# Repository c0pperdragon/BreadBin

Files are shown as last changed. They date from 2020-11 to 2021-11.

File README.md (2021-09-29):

# BreadBin computer
A CPU made of 7400 logic on breadboards - inside a bread bin ;-) 

## Current design 

After various experiments and failed attempts to design a 7400-based computer, I came to a quite minimalistic
8-bit approach which is nevertheless pretty versatile and can utilize a surprisingly large amount of memory
resources. The CPU core itself executes its program from a static 64K flash memory and can access 32 bytes of
internal RAM (which can be considered registers for all practical purposes). Access to the external memory 
area (up to 16MB of address space) allows addition of RAM, ROM and memory mapped IO. In the current setup this
directly mirrors the capabilities of my [OS816 reference design](https://github.com/c0pperdragon/OS816).

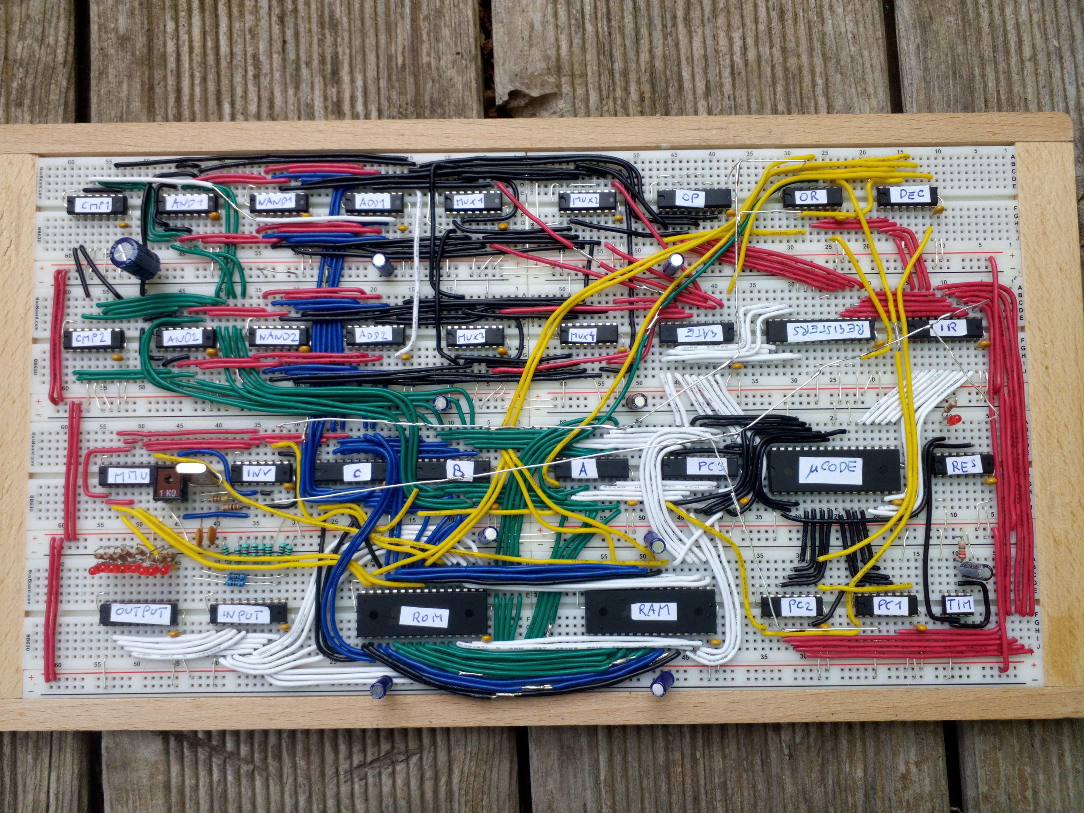
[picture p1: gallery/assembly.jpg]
Breadboard build


## Computer case

With the CPU already built so nicely on an actual wooden board, I had the idea to put it together with
the rest of the computer into a matching bread bin. Because the machine will not require any ventilation this
will keep the dust out quite reliably.

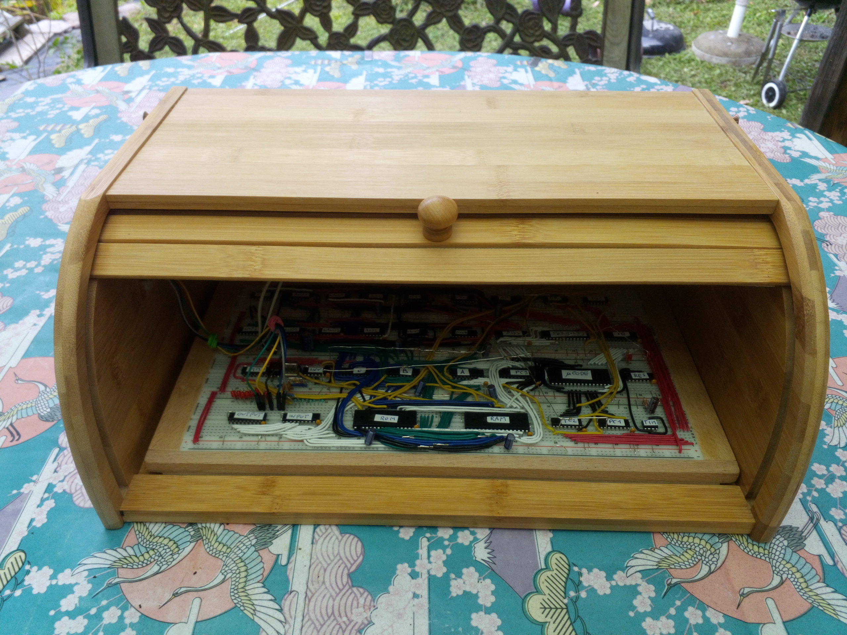
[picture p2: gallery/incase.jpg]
In wooden bread bin

 
## On bread boards

Since a very long time I wanted to design my own CPU and build it from smaller parts, preferable 
on bread boards. My main problem with the approach were my bad experiences with bread boards as a whole,
as they seemed to be too unreliable for anything more serious than arduino tinkering.
As it turns out it is only a matter of using high-quality boards and cabling to get a reliably working
build. The boards I now use (BB830 from BusBoard) are quite expensive, but worth every penny 
and give me very little trouble.

In previous attempts I had much trouble to get a stable ground reference accross all the individual boards.
So this time I directly soldered together ground rails of parallel boards with silver wire on the bottom
and then placed the boards on top of a large plane of aluminium foil. This foil should make good contact to all
the silver ground wires to connect them together and additionally work as shielding. 
So far this works pretty good.

When using this kind of setup it is important to also use a matching logic family of chips. 74AC, 74ACT, 74LVC or 
others have a very fast switching characteristics. This is great for many applications but in a large build with
long and unshielded cables, their brutally steep signal edges wreck havoc with signal integritiy.
So I settled for the moderately fast and well-behaved 74HC logic ICs with only a few 74AC parts to speed up the ALU.

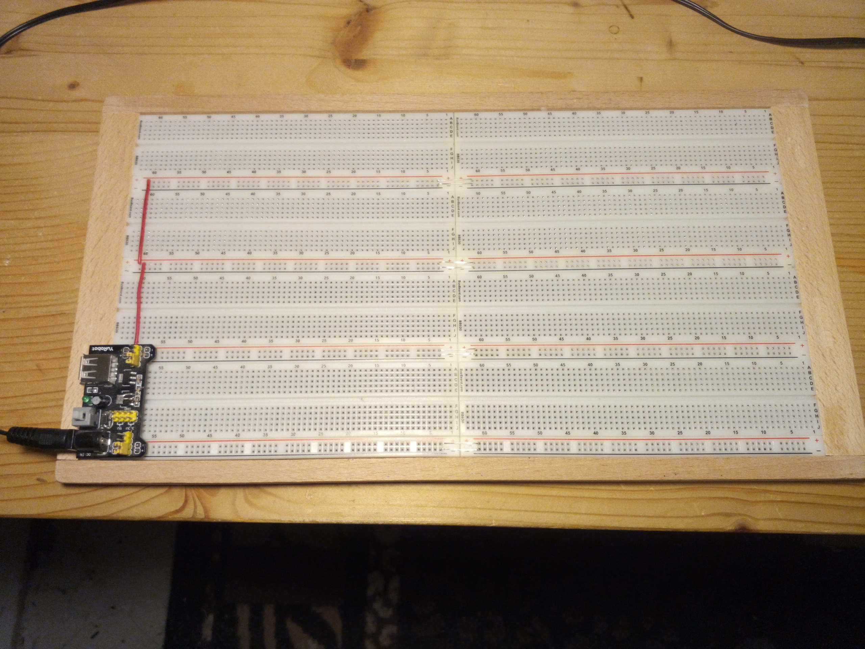
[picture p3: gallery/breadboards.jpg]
Bread boards


## Software

One of the hardest parts of home-made computers is to actually build all the software to make the machine useful.
To get the benefit of existing software, the breadboard computer core is designed to emulate the existing CPU
65C816. Together with 512K RAM and 512K Flash and identical IO capabilities, this now is a completely software 
compatible replica of the OS816 system - running at a lower overall speed, of course.

To properly stay in the "bread" theme, the emulator is called [Bernd](bernd) or BER/ND (if you like a 
more technical appearance). People familiar with the german TV station "Kinderkanal" will recognize the reference.

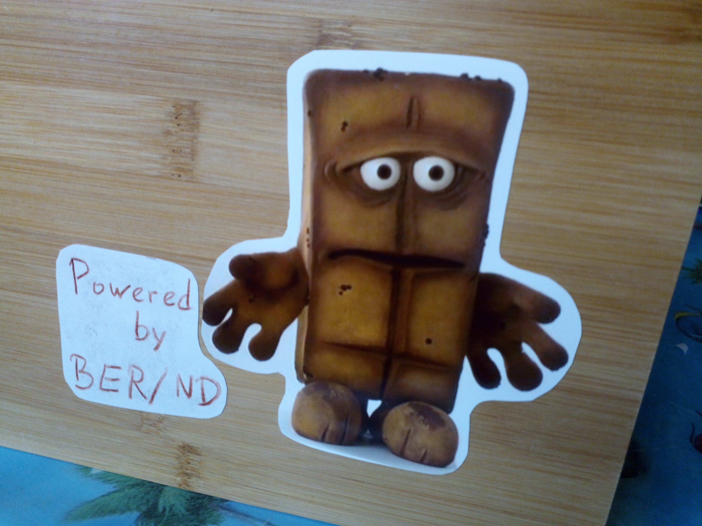
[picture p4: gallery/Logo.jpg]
Bernd logo


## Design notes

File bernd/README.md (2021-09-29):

# BreadBin Emulation Runtime / Nearly Documented

For the BreadBin to be able to execute useful code, it can run BER/ND, which is an instruction-level
emulation of the 65C816 CPU. Execution speed is of course pretty slow compared to a real 65C816, 
but you would not expect top-performance from a bread with such short arms and legs. 
But as long as it gets the job done eventually, this is totally fine by me.

## Unsupported features

To keep the complexity down for the specific purpose of running C programs on the breadbin computer,
some rarely used features and unused features are ommited.

* Emulation mode
* Interrupts (and I flag)
* Decimal mode (and D flag)

## Missing instructions

As a consequence of unsupported features, some opcodes would result in a wrong behaviour.
These opcodes are by design missing from the Bernd emulator and will just cause an immediate processor halt. 

* COP (co-processor interrupt) 
* PLP attempting to set D or I 
* RTI (return from interrupt)
* SED (set decimal)
* SEP attempting to set D or I
* WAI (wait for interrupt)
* XCE attempting to turn on emulation

## Special handling of BRK

As it happens, the BRK instruction has the opcode $00. Executing this opcode causes the Bernd
emulator just to restart, which also resets the emulated 65c816 processor.

## Special use of XCE

Even though emulation is missing and the E flag is not implemented, programms still
need to be able to use the XCE instruction to get into native mode when running on a genuine
65C816 processor. 
To allow this, the XCE instruction when executed by Bernd, is only permitted
to turn off emulation and it will otherwise halt execution.
Additionally it is permitted to turn off emulation repeatedly in which case
the resulting C flag will always be set in the Bernd environment (contrary to 
what it would do on the real processor). 
With this a program can detect when it is running in the Bernd emulator without additional 
preparations.

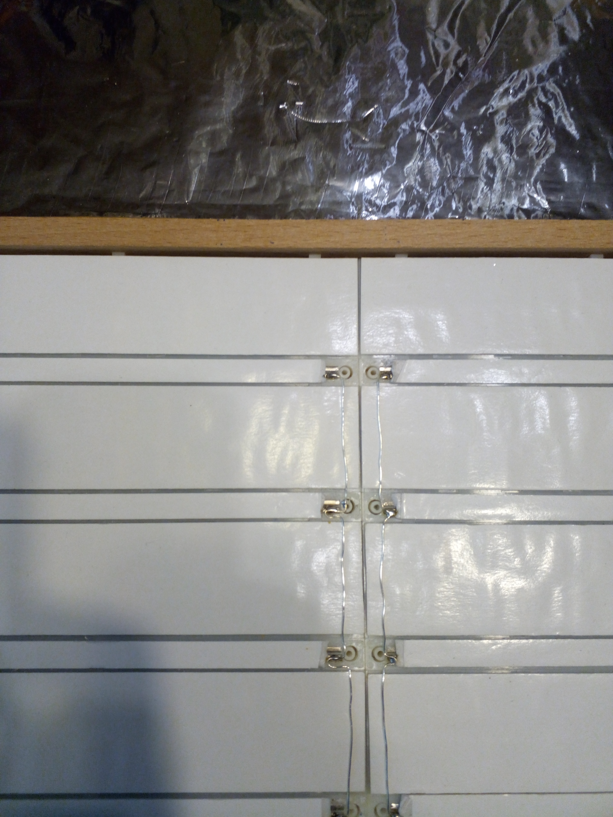
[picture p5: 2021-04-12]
gallery/groundplane.jpg

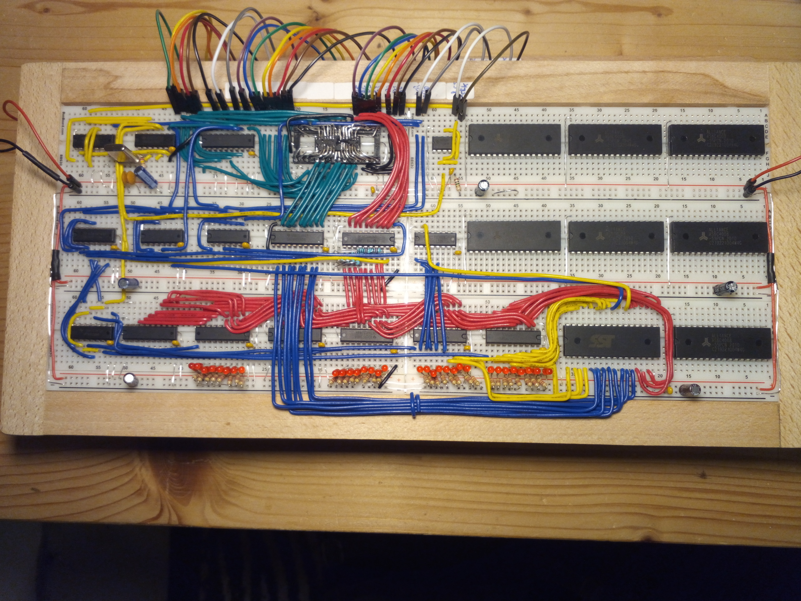
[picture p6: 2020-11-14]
gallery/SystemBoard.jpg

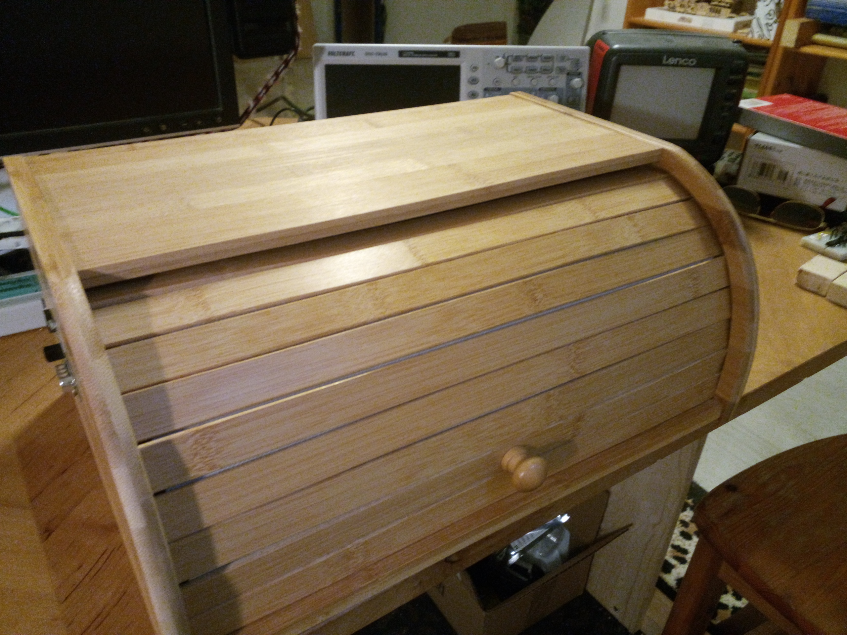
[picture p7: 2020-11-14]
gallery/Case.jpg

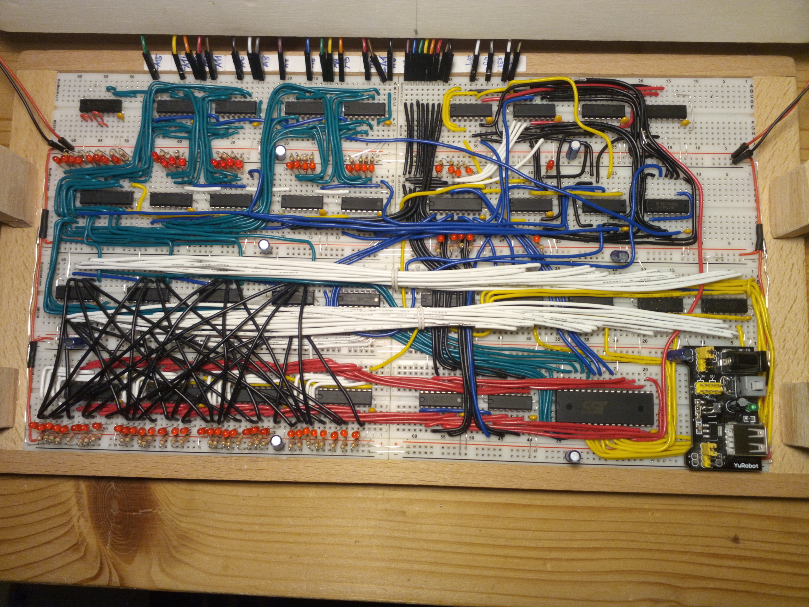
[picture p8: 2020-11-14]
gallery/CPU.jpg

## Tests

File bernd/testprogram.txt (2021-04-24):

; Small test program to use various aspects of the 65C816 to be emulated by Bernd.
; It is small enough so that I do not even use an assembler.
; The program tries to use different parts of the ROM and different parts of the RAM for read and write.
; It also accesses the input and the output port to check if all bits are working.

808000 80 C0 60 30 18 0C 06 03 01 03 06 0C 18 30 60 C0  ; pattern sequence

80FF00 A9 00          LDA #$00         ; initialize counter
80FF02 85 00          STA $00  

80FF04 A5 00          LDA $00          ; read counter from low RAM
80FF06 18             CLC              ; increment up to 15 
80FF07 69 01          ADC #1
80FF09 29 0F          AND #$0F
80FF0B 85 00          STA $00          ; write incremented counter to low RAM
80FF0D AA             TAX

80FF0E A9 40          LDA #$40         ; set up 3. byte of access pointer
80FF10 85 02          STA $02          

80FF12 BF 00 80 80    LDA $808000,X    ; fetch output pattern from ROM
80FF16 8F FF FF 07    STA $07FFFF      ; write to high RAM
80FF2A AF FF FF 07    LDA $07FFFF      ; read from high RAM

80FF1E 2F 00 00 40    AND $400000      ; merge with input data
80FF22 85 01          STA $01          ; set up 2. byte of access pointer, but keep in A also
80FF24 87 00          STA [$00]        ; write via access pointer to output port

80FF26 A9 05          LDA #5           ; waiting loop
80FF28 A0 C8      w0: LDY #200
80FF2A A2 C8      w1: LDX #200
80FF2C E8         w2: INX
80FF2D D0 FD          BNE w2
80FF2F C8             INY
80FF30 D0 F8          BNE w1
80FF32 38             SEC 
80FF33 E9 01          SBC #1
80FF35 D0 F1          BNE w0

80FF37 5C 04 FF 80    JMP $80FF04
          
; Bootstrap code to switch to native mode that can access all RAM and all ROM.
; For Bernd emulation this would not be necessary, but it does not hurt, either.
80FFF0 18             CLC     
80FFF1 FB             XCE              ; turn off emulation mode (X and M flags are still 1)
80FFF2 5C 00 FF 80    JMP $80FF00      ; start user program
80FFF6 FF FF
80FFF8 5C F0 FF 80    JMP $80FFF0      ; first instruction after reset -> jump to native mode ROM area 
80FFFC F8 FF                           ; reset vector is pointing to the initial long jump in bank 0

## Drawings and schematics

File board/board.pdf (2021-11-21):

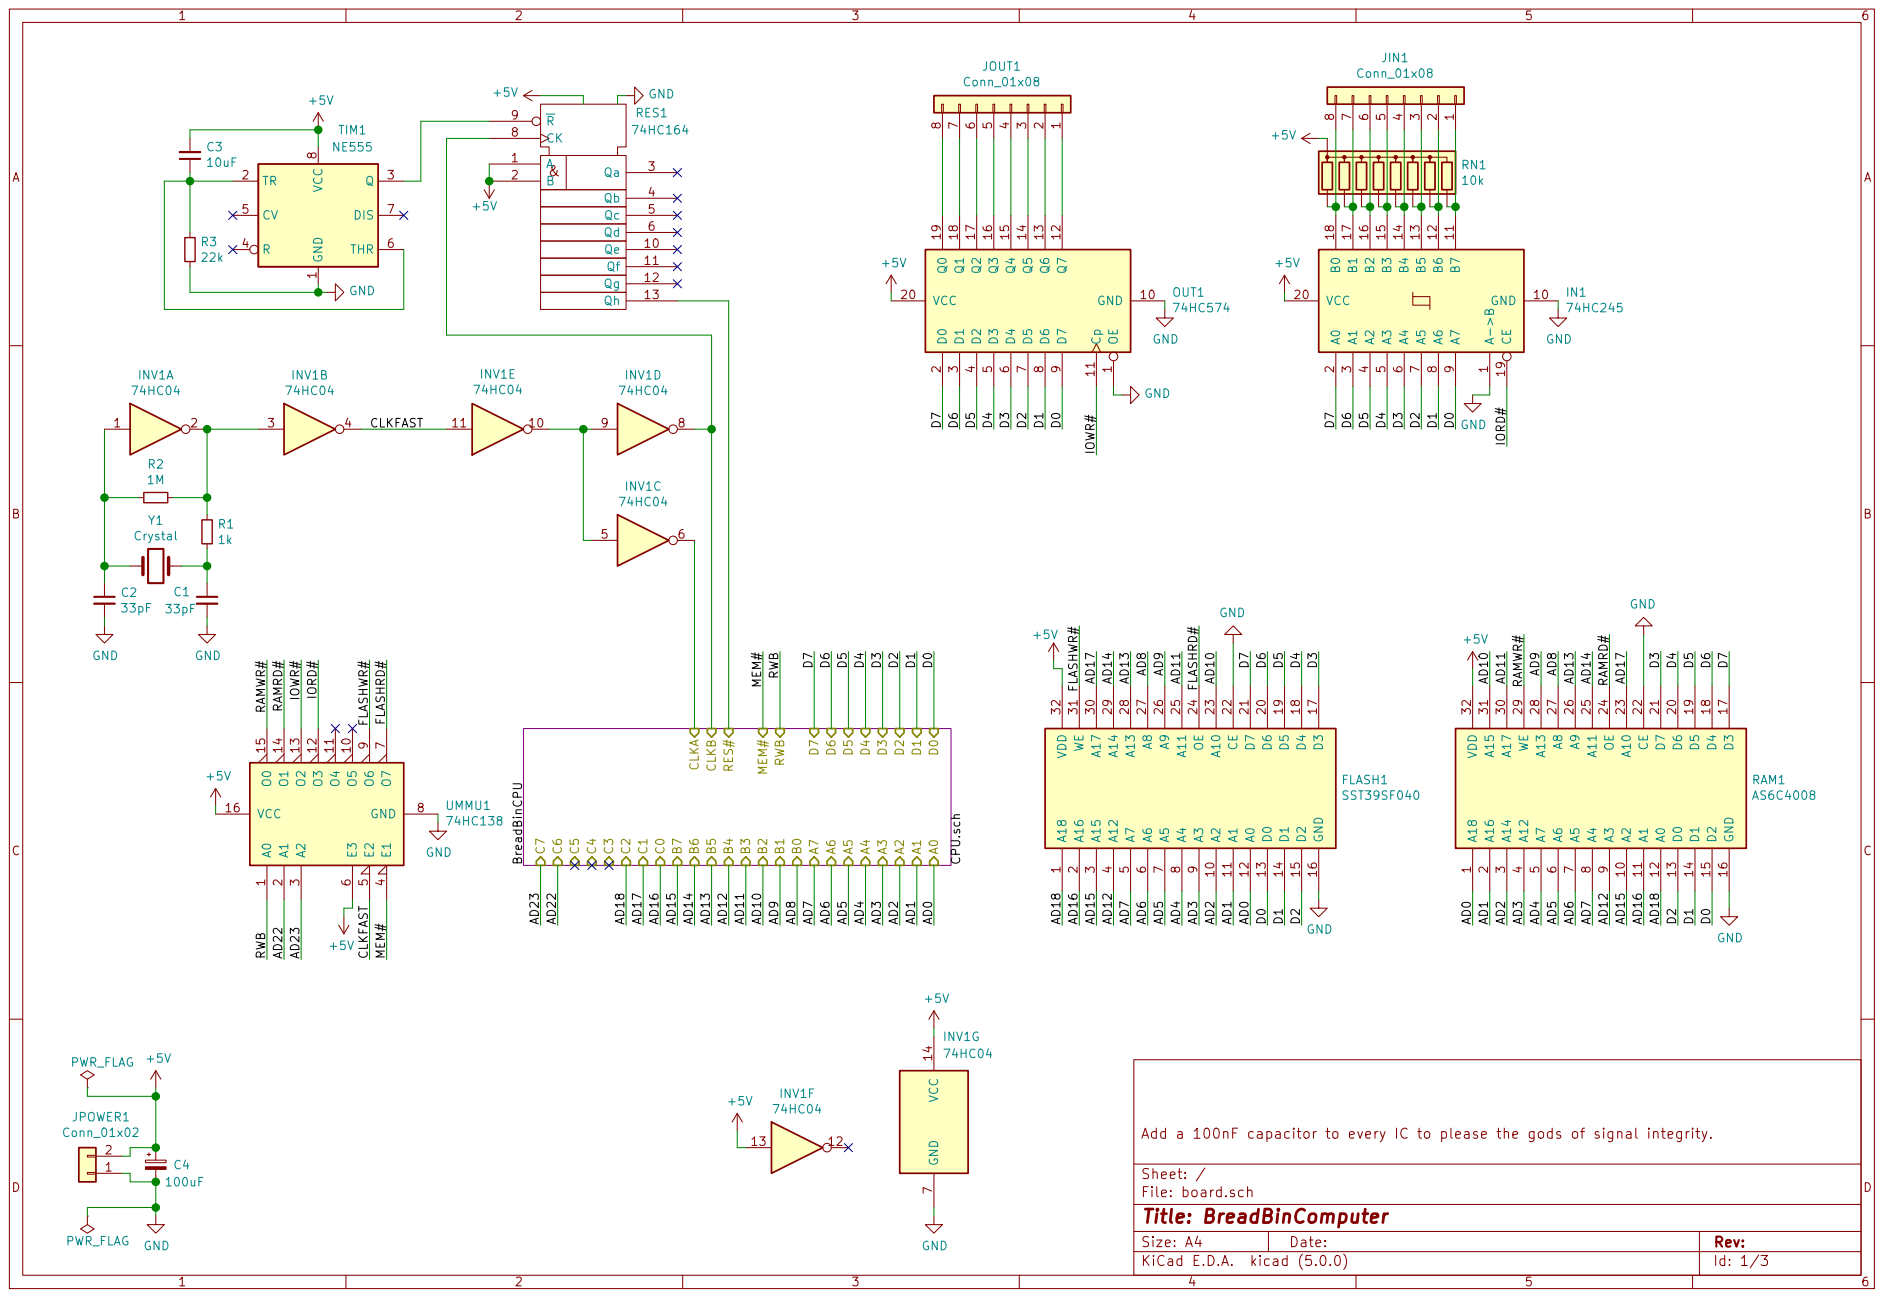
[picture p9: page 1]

Id: 1/3 Title: BreadBinComputer File: board.sch Sheet: / Add a 100nF capacitor to every IC to please the gods of signal integrity. GND

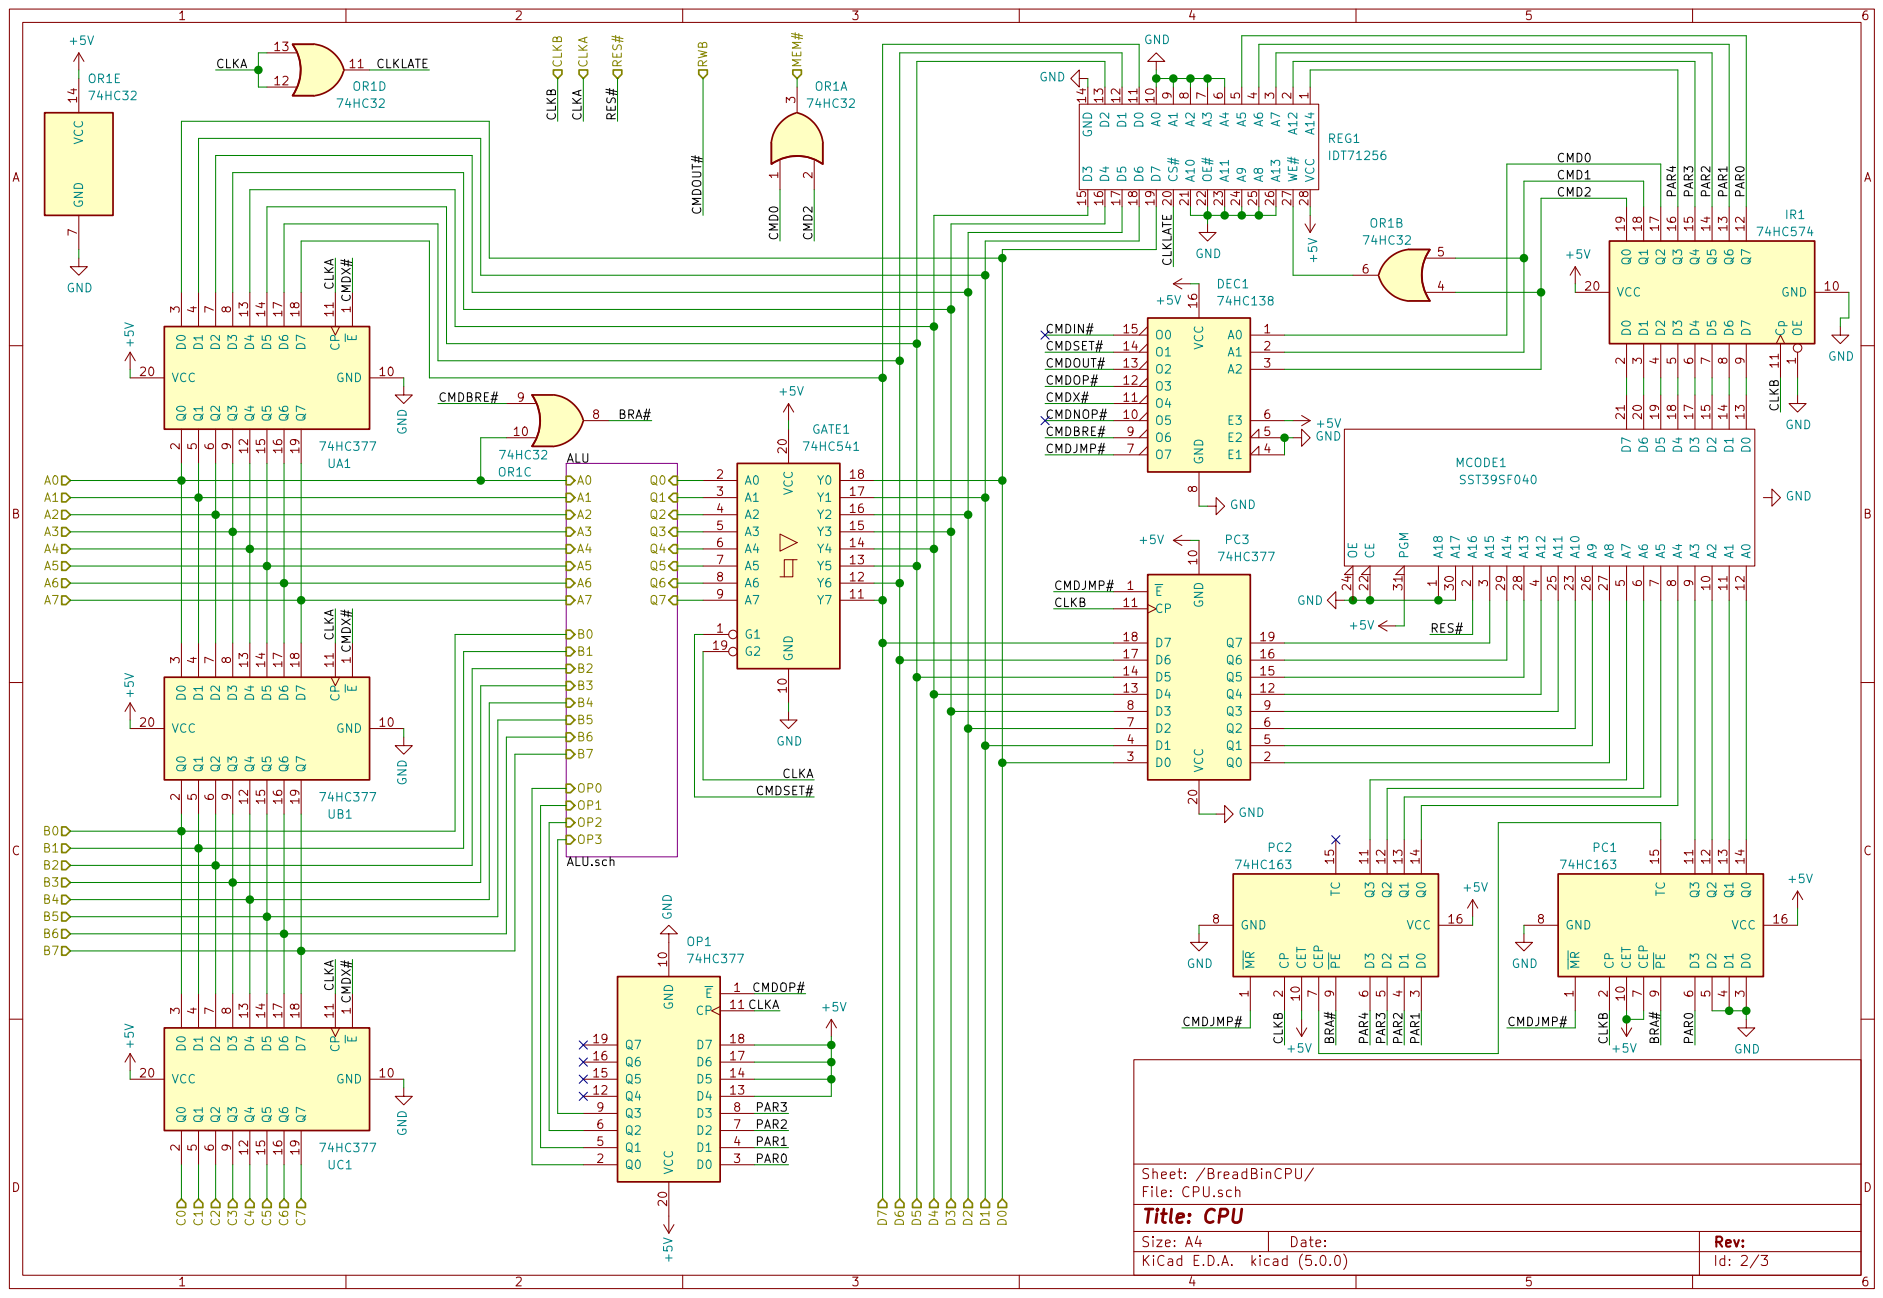
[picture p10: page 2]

2 CS# 20 A10 21 OE# 22 A11 23 A9 24 A8 25 A13 26 WE# 27 VCC 28 A7

1 CET 10 Q3 11 Q2 12 Q1 13 Q0 14 TC 15 VCC 16 CP

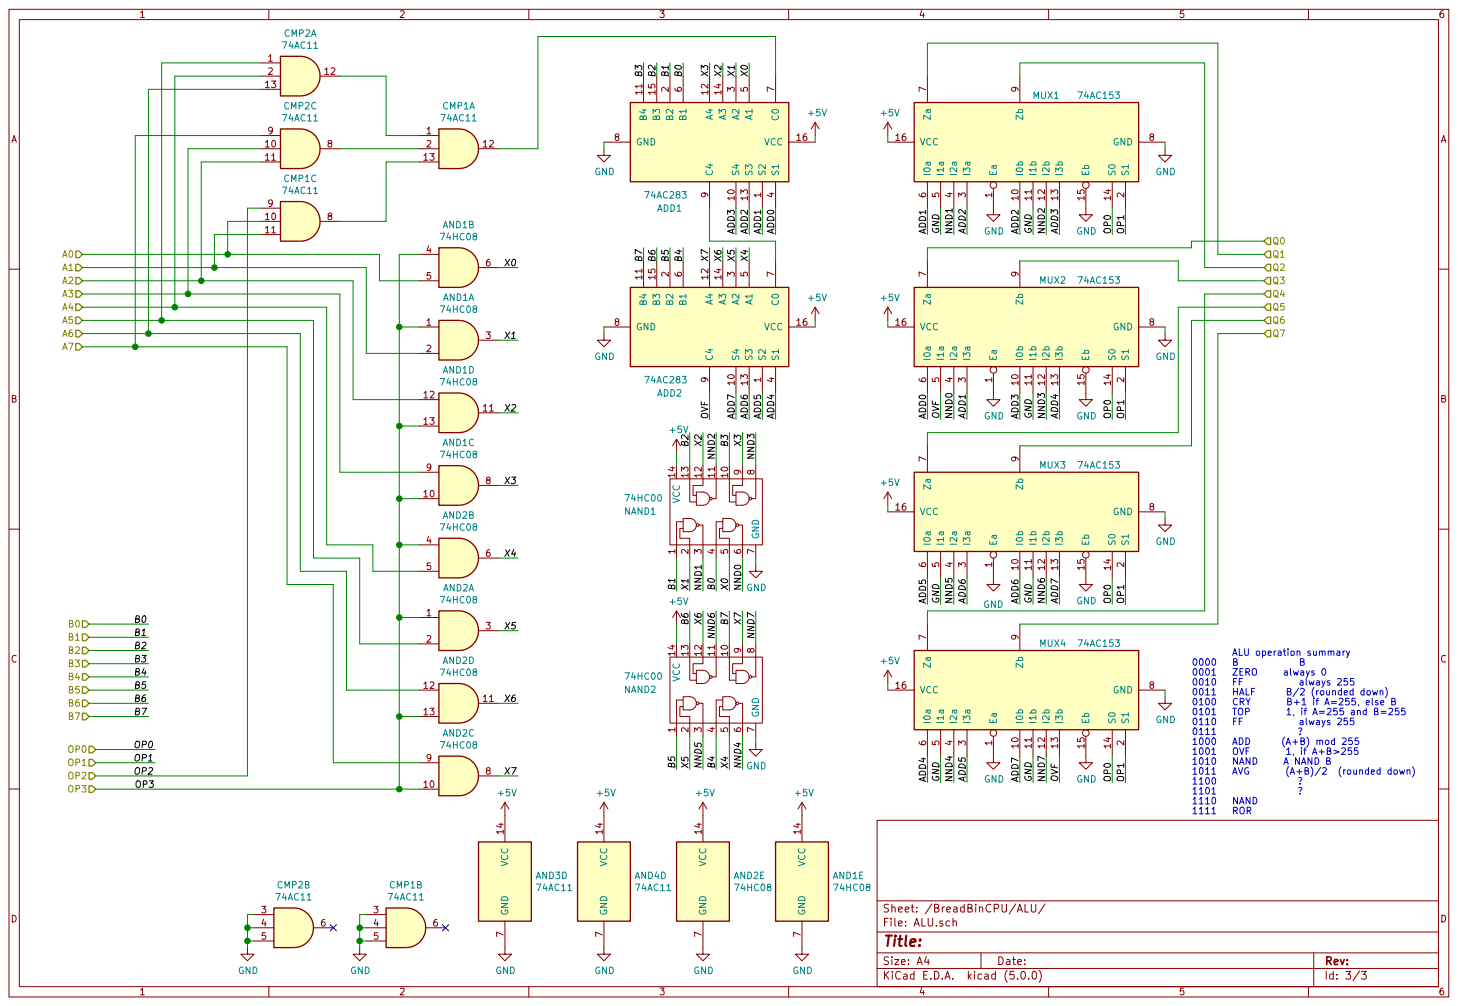
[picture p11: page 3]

Id: 3/3 Title: File: ALU.sch Sheet: /BreadBinCPU/ALU/

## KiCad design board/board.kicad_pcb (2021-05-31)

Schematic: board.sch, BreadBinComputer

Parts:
C1, C2: 33pF; C_Disc_D4.7mm_W2.5mm_P5.00mm
C3: 10uF; C_Disc_D4.7mm_W2.5mm_P5.00mm
C4: 100uF; CP_Radial_D10.0mm_P5.00mm
IN1: 74HC245; DIP-20_W7.62mm
INV1: 74HC04; DIP-14_W7.62mm
JIN1: Conn_01x08; PinHeader_1x08_P2.54mm_Vertical
JOUT1: Conn_01x08; PinHeader_1x08_P2.54mm_Vertical
JPOWER1: Conn_01x02; PinHeader_1x02_P2.54mm_Vertical
OR2: 74HC32; DIP-14_W7.62mm
OUT1: 74HC574; DIP-20_W7.62mm
R1: 1k; R_Axial_DIN0204_L3.6mm_D1.6mm_P7.62mm_Horizontal
R2: 1M; R_Axial_DIN0204_L3.6mm_D1.6mm_P7.62mm_Horizontal
R3: 33k; R_Axial_DIN0204_L3.6mm_D1.6mm_P7.62mm_Horizontal
RAM1: AS6C4008; DIP-32_W15.24mm
RES1: 74HC164; DIP-14_W7.62mm
RN1: 10k; R_Array_SIP9
ROM1: SST39SF040; DIP-32_W15.24mm
TIM1: NE555; DIP-8_W7.62mm
Y1: Crystal; Crystal_HC18-U_Vertical

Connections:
/AD0: RAM1.1, ROM1.12; also elsewhere on the board
/AD1: RAM1.2, ROM1.11; also elsewhere on the board
/AD2: RAM1.3, ROM1.10; also elsewhere on the board
/AD3: RAM1.4, ROM1.9; also elsewhere on the board
/AD4: RAM1.5, ROM1.8; also elsewhere on the board
/AD5: RAM1.6, ROM1.7; also elsewhere on the board
/AD6: RAM1.7, ROM1.6; also elsewhere on the board
/AD7: RAM1.8, ROM1.5; also elsewhere on the board
/AD8: RAM1.27, ROM1.27; also elsewhere on the board
/AD9: RAM1.28, ROM1.26; also elsewhere on the board
/AD10: RAM1.31, ROM1.23; also elsewhere on the board
/AD11: RAM1.30, ROM1.25; also elsewhere on the board
/AD12: RAM1.9, ROM1.4; also elsewhere on the board
/AD13: RAM1.26, ROM1.28; also elsewhere on the board
/AD14: RAM1.25, ROM1.29; also elsewhere on the board
/AD15: RAM1.10, ROM1.3; also elsewhere on the board
/AD16: RAM1.11, ROM1.2; also elsewhere on the board
/AD17: RAM1.23, ROM1.30; also elsewhere on the board
/AD18: RAM1.12, ROM1.1; also elsewhere on the board
/AD22: INV1.13, OR2.1; also elsewhere on the board
/AD23: INV1.11, OR2.2, OR2.4; also elsewhere on the board
/BreadBinCPU/CLK: INV1.6, RES1.8; also elsewhere on the board
/BreadBinCPU/RES#: RES1.13; also elsewhere on the board
/D0: IN1.9 (A7), OUT1.9, RAM1.13, ROM1.13; also elsewhere on the board
/D1: IN1.8 (A6), OUT1.8, RAM1.14, ROM1.14; also elsewhere on the board
/D2: IN1.7 (A5), OUT1.7, RAM1.15, ROM1.15; also elsewhere on the board
/D3: IN1.6 (A4), OUT1.6, RAM1.17, ROM1.17; also elsewhere on the board
/D4: IN1.5 (A3), OUT1.5, RAM1.18, ROM1.18; also elsewhere on the board
/D5: IN1.4 (A2), OUT1.4, RAM1.19, ROM1.19; also elsewhere on the board
/D6: IN1.3 (A1), OUT1.3, RAM1.20, ROM1.20; also elsewhere on the board
/D7: IN1.2 (A0), OUT1.2, RAM1.21, ROM1.21; also elsewhere on the board
/IOSEL#: OR2.6, OR2.9, OR2.12
/RAMSEL#: OR2.3, RAM1.22
/RD#: OR2.13, RAM1.24, ROM1.24; also elsewhere on the board
/ROMSEL#: INV1.10, ROM1.22
/WR#: OR2.10, RAM1.29, ROM1.31; also elsewhere on the board
unnamed: C1.1, R1.2, Y1.2
unnamed: C2.1, INV1.1, R2.2, Y1.1
unnamed: C3.1, R3.1, TIM1.2 (TR), TIM1.6 (THR)
unnamed: IN1.11 (B7), JIN1.1, RN1.9
unnamed: IN1.12 (B6), JIN1.2, RN1.8
unnamed: IN1.13 (B5), JIN1.3, RN1.7
unnamed: IN1.14 (B4), JIN1.4, RN1.6
unnamed: IN1.15 (B3), JIN1.5, RN1.5
unnamed: IN1.16 (B2), JIN1.6, RN1.4
unnamed: IN1.17 (B1), JIN1.7, RN1.3
unnamed: IN1.18 (B0), JIN1.8, RN1.2
unnamed: IN1.19 (CE), OR2.11
unnamed: INV1.2, INV1.3, R1.1, R2.1
unnamed: INV1.4, INV1.5, INV1.9
unnamed: INV1.12, OR2.5
unnamed: JOUT1.1, OUT1.12
unnamed: JOUT1.2, OUT1.13
unnamed: JOUT1.3, OUT1.14
unnamed: JOUT1.4, OUT1.15
unnamed: JOUT1.5, OUT1.16
unnamed: JOUT1.6, OUT1.17
unnamed: JOUT1.7, OUT1.18
unnamed: JOUT1.8, OUT1.19
unnamed: OR2.8, OUT1.11
unnamed: RES1.9, TIM1.3 (Q)

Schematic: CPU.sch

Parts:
DEC1: 74HC138; DIP-16_W7.62mm
GATE1: 74HC541; DIP-20_W7.62mm
IR1: 74HC574; DIP-20_W7.62mm
MCODE1: SST39SF040; DIP-32_W15.24mm
OP1: 74HC377; DIP-20_W7.62mm
OR1: 74HC32; DIP-14_W7.62mm
PC1, PC2: 74HC163; DIP-16_W7.62mm
PC3: 74HC377; DIP-20_W7.62mm
REG1: IDT71256; DIP-28_W7.62mm
UA1: 74HC377; DIP-20_W7.62mm
UB1: 74HC377; DIP-20_W7.62mm
UC1: 74HC377; DIP-20_W7.62mm

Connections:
/AD0: OR1.10, UA1.2, UB1.3; also elsewhere on the board
/AD1: UA1.5, UB1.4; also elsewhere on the board
/AD2: UA1.6, UB1.7; also elsewhere on the board
/AD3: UA1.9, UB1.8; also elsewhere on the board
/AD4: UA1.12, UB1.13; also elsewhere on the board
/AD5: UA1.15, UB1.14; also elsewhere on the board
/AD6: UA1.16, UB1.17; also elsewhere on the board
/AD7: UA1.19, UB1.18; also elsewhere on the board
/AD8: UB1.2, UC1.3; also elsewhere on the board
/AD9: UB1.5, UC1.4; also elsewhere on the board
/AD10: UB1.6, UC1.7; also elsewhere on the board
/AD11: UB1.9, UC1.8; also elsewhere on the board
/AD12: UB1.12, UC1.13; also elsewhere on the board
/AD13: UB1.15, UC1.14; also elsewhere on the board
/AD14: UB1.16, UC1.17; also elsewhere on the board
/AD15: UB1.19, UC1.18; also elsewhere on the board
/AD16: UC1.2; also elsewhere on the board
/AD17: UC1.5; also elsewhere on the board
/AD18: UC1.6; also elsewhere on the board
/AD22: UC1.16; also elsewhere on the board
/AD23: UC1.19; also elsewhere on the board
/BreadBinCPU/ALU/OP0: OP1.9; also elsewhere on the board
/BreadBinCPU/ALU/OP1: OP1.6; also elsewhere on the board
/BreadBinCPU/ALU/OP2: OP1.5; also elsewhere on the board
/BreadBinCPU/ALU/OP3: OP1.2; also elsewhere on the board
/BreadBinCPU/ALU/Q0: GATE1.2 (A0); also elsewhere on the board
/BreadBinCPU/ALU/Q1: GATE1.3 (A1); also elsewhere on the board
/BreadBinCPU/ALU/Q2: GATE1.4 (A2); also elsewhere on the board
/BreadBinCPU/ALU/Q3: GATE1.5 (A3); also elsewhere on the board
/BreadBinCPU/ALU/Q4: GATE1.6 (A4); also elsewhere on the board
/BreadBinCPU/ALU/Q5: GATE1.7 (A5); also elsewhere on the board
/BreadBinCPU/ALU/Q6: GATE1.8 (A6); also elsewhere on the board
/BreadBinCPU/ALU/Q7: GATE1.9 (A7); also elsewhere on the board
/BreadBinCPU/BRA#: OR1.8, PC1.9 (~PE), PC2.9 (~PE)
/BreadBinCPU/C3: UC1.9
/BreadBinCPU/C4: UC1.12
/BreadBinCPU/C5: UC1.15
/BreadBinCPU/CLK: GATE1.1 (G1), IR1.11, OP1.11, OR1.1, OR1.12, PC1.2 (CP), PC2.2 (CP), PC3.11, REG1.20, UA1.11, UB1.11, UC1.11; also elsewhere on the board
/BreadBinCPU/CMD0: DEC1.1, IR1.17
/BreadBinCPU/CMD1: DEC1.2, IR1.18, OR1.5
/BreadBinCPU/CMD2: DEC1.3, IR1.19, OR1.4
/BreadBinCPU/CMDBRE#: DEC1.9, OR1.9
/BreadBinCPU/CMDIN#: DEC1.14, OR1.13
/BreadBinCPU/CMDJMP#: DEC1.7, PC1.1 (~MR), PC2.1 (~MR), PC3.1
/BreadBinCPU/CMDOP#: DEC1.12, OP1.1
/BreadBinCPU/CMDOUT#: DEC1.13, OR1.2
/BreadBinCPU/CMDSET#: DEC1.15, GATE1.19 (G2)
/BreadBinCPU/CMDX#: DEC1.11, UA1.1, UB1.1, UC1.1
/BreadBinCPU/PAR0: IR1.12, OP1.8, PC1.6 (D3), REG1.5
/BreadBinCPU/PAR1: IR1.13, OP1.7, PC2.3 (D0), REG1.4
/BreadBinCPU/PAR2: IR1.14, OP1.4, PC2.4 (D1), REG1.3
/BreadBinCPU/PAR3: IR1.15, OP1.3, PC2.5 (D2), REG1.2
/BreadBinCPU/PAR4: IR1.16, PC2.6 (D3), REG1.1
/BreadBinCPU/RES#: MCODE1.2; also elsewhere on the board
/D0: GATE1.18 (Y0), PC3.3, REG1.19, UA1.3; also elsewhere on the board
/D1: GATE1.17 (Y1), PC3.4, REG1.18, UA1.4; also elsewhere on the board
/D2: GATE1.16 (Y2), PC3.7, REG1.17, UA1.7; also elsewhere on the board
/D3: GATE1.15 (Y3), PC3.8, REG1.16, UA1.8; also elsewhere on the board
/D4: GATE1.14 (Y4), PC3.13, REG1.15, UA1.13; also elsewhere on the board
/D5: GATE1.13 (Y5), PC3.14, REG1.13, UA1.14; also elsewhere on the board
/D6: GATE1.12 (Y6), PC3.17, REG1.12, UA1.17; also elsewhere on the board
/D7: GATE1.11 (Y7), PC3.18, REG1.11, UA1.18; also elsewhere on the board
/RD#: OR1.11; also elsewhere on the board
/WR#: OR1.3; also elsewhere on the board
unnamed: IR1.2, MCODE1.21
unnamed: IR1.3, MCODE1.20
unnamed: IR1.4, MCODE1.19
unnamed: IR1.5, MCODE1.18
unnamed: IR1.6, MCODE1.17
unnamed: IR1.7, MCODE1.15
unnamed: IR1.8, MCODE1.14
unnamed: IR1.9, MCODE1.13
unnamed: MCODE1.3, PC3.19
unnamed: MCODE1.4, PC3.12
unnamed: MCODE1.5, PC2.11 (Q3)
unnamed: MCODE1.6, PC2.12 (Q2)
unnamed: MCODE1.7, PC2.13 (Q1)
unnamed: MCODE1.8, PC2.14 (Q0)
unnamed: MCODE1.9, PC1.11 (Q3)
unnamed: MCODE1.10, PC1.12 (Q2)
unnamed: MCODE1.11, PC1.13 (Q1)
unnamed: MCODE1.12, PC1.14 (Q0)
unnamed: MCODE1.23, PC3.6
unnamed: MCODE1.25, PC3.9
unnamed: MCODE1.26, PC3.5
unnamed: MCODE1.27, PC3.2
unnamed: MCODE1.28, PC3.15
unnamed: MCODE1.29, PC3.16
unnamed: OR1.6, REG1.27
unnamed: PC1.15 (TC), PC2.7 (CEP)

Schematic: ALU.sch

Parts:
ADD1, ADD2: 74AC283; DIP-16_W7.62mm
AND1, AND2: 74AC08; DIP-14_W7.62mm
AND3, AND4: 74AC11; DIP-14_W7.62mm
LOGIC1, LOGIC2: 74AC00; DIP-14_W7.62mm
MUX1, MUX2, MUX3, MUX4: 74AC153; DIP-16_W7.62mm

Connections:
/AD0: AND1.1, AND3.10; also elsewhere on the board
/AD1: AND1.4, AND3.9; also elsewhere on the board
/AD2: AND1.9, AND3.5; also elsewhere on the board
/AD3: AND1.12, AND3.4; also elsewhere on the board
/AD4: AND2.1, AND3.3; also elsewhere on the board
/AD5: AND2.4, AND3.13; also elsewhere on the board
/AD6: AND2.9, AND3.2; also elsewhere on the board
/AD7: AND2.12, AND3.1; also elsewhere on the board
/AD8: ADD1.6, LOGIC1.10; also elsewhere on the board
/AD9: ADD1.2, LOGIC1.13; also elsewhere on the board
/AD10: ADD1.15, LOGIC1.4; also elsewhere on the board
/AD11: ADD1.11, LOGIC1.1; also elsewhere on the board
/AD12: ADD2.6, LOGIC2.10; also elsewhere on the board
/AD13: ADD2.2, LOGIC2.13; also elsewhere on the board
/AD14: ADD2.15, LOGIC2.4; also elsewhere on the board
/AD15: ADD2.11, LOGIC2.1; also elsewhere on the board
/BreadBinCPU/ALU/ADD0: ADD1.4, MUX1.6
/BreadBinCPU/ALU/ADD1: ADD1.1, MUX1.10
/BreadBinCPU/ALU/ADD2: ADD1.13, MUX2.6
/BreadBinCPU/ALU/ADD3: ADD1.10, MUX2.10
/BreadBinCPU/ALU/ADD4: ADD2.4, MUX3.6
/BreadBinCPU/ALU/ADD5: ADD2.1, MUX3.10
/BreadBinCPU/ALU/ADD6: ADD2.13, MUX4.6
/BreadBinCPU/ALU/ADD7: ADD2.10, MUX4.10
/BreadBinCPU/ALU/NND0: LOGIC1.8, MUX1.4
/BreadBinCPU/ALU/NND1: LOGIC1.11, MUX1.12
/BreadBinCPU/ALU/NND2: LOGIC1.6, MUX2.4
/BreadBinCPU/ALU/NND3: LOGIC1.3, MUX2.12
/BreadBinCPU/ALU/NND4: LOGIC2.8, MUX3.4
/BreadBinCPU/ALU/NND5: LOGIC2.11, MUX3.12
/BreadBinCPU/ALU/NND6: LOGIC2.6, MUX4.4
/BreadBinCPU/ALU/NND7: LOGIC2.3, MUX4.12
/BreadBinCPU/ALU/OP0: MUX1.14, MUX2.14, MUX3.14, MUX4.14; also elsewhere on the board
/BreadBinCPU/ALU/OP1: MUX1.2, MUX2.2, MUX3.2, MUX4.2; also elsewhere on the board
/BreadBinCPU/ALU/OP2: AND3.11; also elsewhere on the board
/BreadBinCPU/ALU/OP3: AND1.2, AND1.5, AND1.10, AND1.13, AND2.2, AND2.5, AND2.10, AND2.13; also elsewhere on the board
/BreadBinCPU/ALU/OVF: ADD2.9, MUX1.5
/BreadBinCPU/ALU/Q0: MUX1.7; also elsewhere on the board
/BreadBinCPU/ALU/Q1: MUX1.9; also elsewhere on the board
/BreadBinCPU/ALU/Q2: MUX2.7; also elsewhere on the board
/BreadBinCPU/ALU/Q3: MUX2.9; also elsewhere on the board
/BreadBinCPU/ALU/Q4: MUX3.7; also elsewhere on the board
/BreadBinCPU/ALU/Q5: MUX3.9; also elsewhere on the board
/BreadBinCPU/ALU/Q6: MUX4.7; also elsewhere on the board
/BreadBinCPU/ALU/Q7: MUX4.9; also elsewhere on the board
/BreadBinCPU/ALU/X0: ADD1.5, AND1.3, LOGIC1.9, MUX4.13
/BreadBinCPU/ALU/X1: ADD1.3, AND1.6, LOGIC1.12, MUX4.3
/BreadBinCPU/ALU/X2: ADD1.14, AND1.8, LOGIC1.5, MUX3.13
/BreadBinCPU/ALU/X3: ADD1.12, AND1.11, LOGIC1.2, MUX3.3
/BreadBinCPU/ALU/X4: ADD2.5, AND2.3, LOGIC2.9, MUX2.13
/BreadBinCPU/ALU/X5: ADD2.3, AND2.6, LOGIC2.12, MUX2.3
/BreadBinCPU/ALU/X6: ADD2.14, AND2.8, LOGIC2.5, MUX1.13
/BreadBinCPU/ALU/X7: ADD2.12, AND2.11, LOGIC2.2, MUX1.3
unnamed: ADD1.7, AND4.12
unnamed: ADD1.9, ADD2.7
unnamed: AND3.6, AND4.2
unnamed: AND3.8, AND4.13
unnamed: AND3.12, AND4.1

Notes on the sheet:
ALU operation summary 0000 B 0001 ZERO 0010 FF 0011 ZERO 0100 CRY B+1 if A=255, else B 0101 TOP 1, if A=255 and B=255 0110 FF 0111 ZERO 1000 ADD (A+B) mod 255 1001 OVF 1, if A+B>255 1010 NAND A NAND B 1011 REV revert bit order of A 1100 CRY1 A+B+1 if A=255, else A+B 1101 OVF1 1, if A+B+1>255 1110 N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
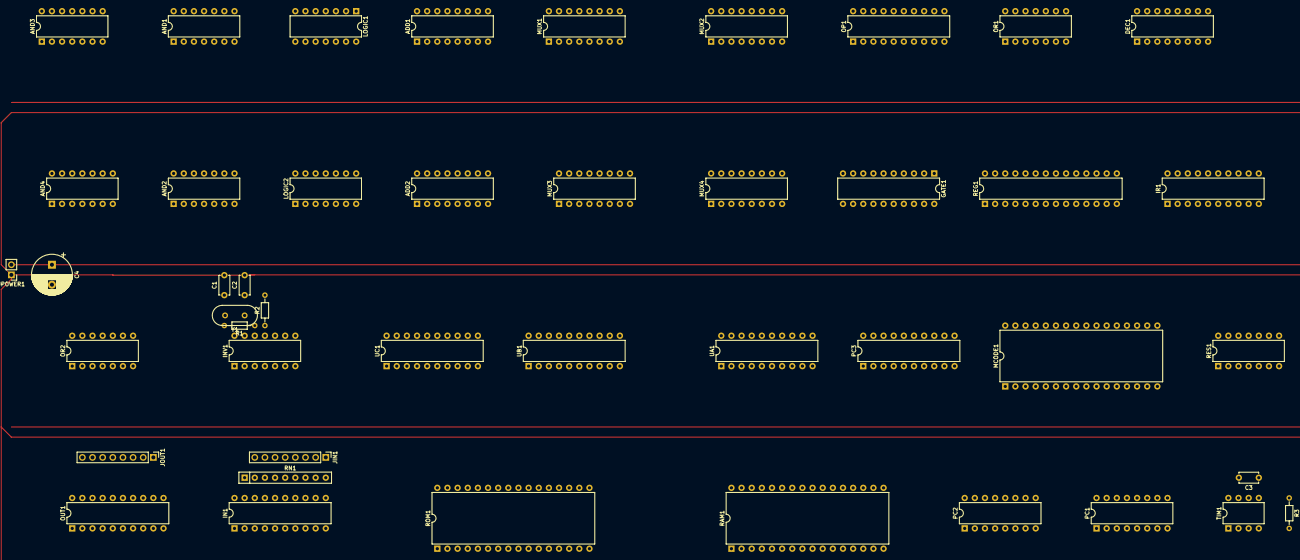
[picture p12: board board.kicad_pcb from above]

Board: 2 copper layers, 45 parts (0 on the bottom side), 147 nets.

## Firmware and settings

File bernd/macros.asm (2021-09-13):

; Collection of macros. For best interoperability, these macros 
; specify the temporary variables they use.
; Additionally all macros (except the branch macros themselves) are required to cause
; no side-effects besides setting operation or operands when only the first instruction is executed. 
; This is to allow for preceeding branch instructions that have a delayed branch.

; perform a branch if the A/M flag is set to 16 bit mode
MACRO BRACCU16 branchtarget                 ; 2
    X MFLAG
    BRE branchtarget
ENDMACRO

; perform a branch if the X flag is set to 16 bit mode
MACRO BRINDEX16 branchtarget
    X XFLAG
    BRE branchtarget
ENDMACRO


; provide the source value on the ALU output for setting
MACRO GET source
    OP ADD
    X source
    X V0
ENDMACRO  

; quick way to provide various constants on the ALU output
MACRO GET0
    OP ZERO
ENDMACRO
MACRO GET1
    GET V1
ENDMACRO
MACRO GET128
    GET V128
ENDMACRO
MACRO GET255
    OP FF
ENDMACRO

; load a value from the specified memory location and bank 
; and increment location (but not bank) afterwards
MACRO LOAD_POSTINC rlo rhi bank value
    X bank
    X rhi
    X rlo
    OP CRY
    IN value
    SET rhi
    X V255
    SET rlo
ENDMACRO 

; store a value to the specified memory location and bank 
; and increment location (but not bank) afterwards
MACRO STORE_POSTINC rlo rhi bank value
    X bank
    X rhi
    X rlo
    OUT value
    OP CRY
    SET rhi
    X V255
    SET rlo
ENDMACRO 

   
; Fetch the next operand byte of the program.
; After reading data into the position given as target, increase PC 
MACRO FETCH target      ; = 8
    LOAD_POSTINC PCLO PCHI PBR target
ENDMACRO

; increment program counter without fetching data
MACRO SKIP
    INC16 PCLO PCHI
ENDMACRO

; Fetch the next command opcode from the program and
; Jump to the proper firmware segment. increase PC afterwards.
; Intermediate storage: TMP0
MACRO NEXT        ; = 9
    X PBR
    X PCHI
    X PCLO
    OP CRY
    IN TMP0
    SET PCHI
    X V255
    JMP TMP0
    SET PCLO  ; make use of delay slot
ENDMACRO

; Fetch next byte from program and treat this as a relative address
; Set program counter to target and fetch next command from there
; Intermediate storage: all temporaries
MACRO NEXT_RELATIVE                       ; = 41
    FETCH TMP3   ; this is a signed 8-bit offset     ; 8
    ; tricky operation to sign-extend to a 16-bit value
    X TMP3         
    X TMP3         
    OP OVF         
    SET TMP4  ; 0 if positive, 1 if negative
    X TMP4         
    X TMP4       
    OP NAND
    SET TMP4  ; 255 if positive, 254 if negative
    X TMP4
    X V1
    OP ADD    
    SET TMP4  ; 0 if positive, 255 if negative
    ; do the relative jump
    ADD16 PCLO PCHI TMP3 TMP4     ; 12
    NEXT                          ; 9
ENDMACRO


; add a 8-bit value to a 16-bit value
; temporary variable: TMP0  (source may be TMP0)
MACRO ADD16_8 targetlo targethi source
    OP OVF
    X targetlo
    X source
    SET TMP0
    OP ADD
    SET targetlo
    X targethi
    X TMP0
    SET targethi
ENDMACRO

; add two 16-bit values (no carry out or carry in)
; temporary registers: TMP0
MACRO ADD16 targetlo targethi sourcelo sourcehi   ; = 12
    OP OVF
    X targetlo
    X sourcelo
    SET TMP0
    OP ADD
    SET targetlo
    X targethi
    X sourcehi
    SET targethi
    X targethi
    X TMP0
    SET targethi
ENDMACRO

; add a 16-bit value to a 24-bit value (no carry out or carry in)
; temporary registers: TMP0
MACRO ADD24_16 targetlo targethi targetxhi sourcelo sourcehi
    ; combine lower 8 bits
    OP OVF
    X targetlo
    X sourcelo
    SET TMP0
    OP ADD
    SET targetlo
    ADD16_8 targethi targetxhi TMP0
    ADD16_8 targethi targetxhi sourcehi
ENDMACRO


; Increment a 16-bit value and store in new location.
; (target may also be source)
MACRO CPINC16 targetlo targethi sourcelo sourcehi
    OP CRY
    X sourcehi
    X sourcelo
    SET targethi
    X V255
    SET targetlo
ENDMACRO

; Increment a 24-bit value and store in new location
; (target may also be source)
; temporary storage: TMP0
MACRO CPINC24 targetlo targethi targetbank sourcelo sourcehi sourcebank
    X sourcelo
    X sourcehi
    OP TOP
    SET TMP0
    X sourcebank
    X TMP0
    OP ADD
    SET targetbank
    CPINC16 targetlo targethi sourcelo sourcehi
ENDMACRO

; Increment a 16-bit value.
MACRO INC16 rlo rhi
    CPINC16 rlo rhi rlo rhi
ENDMACRO

; Increment a 24-bit value.
; temporary storage : TMP0
MACRO INC24 rlo rhi rbank
    CPINC24 rlo rhi rbank rlo rhi rbank
ENDMACRO

; Decrement a 16-bit value.
; Intermediate registers: TMP0
MACRO DEC16 rlo rhi
    ADD16 rlo rhi V255 V255
ENDMACRO

; increment a register if another register is 0
; Intermediate store TMP0
MACRO INC_IF_ZERO target test
    X test
    X test
    OP NAND
    SET TMP0
    X target
    X TMP0
    OP CRY
    SET target
ENDMACRO

; decrement a register if another register is 255
; Intermediate store TMP0
MACRO DEC_IF_255 target test
    X V255
    X test
    OP CRY
    SET TMP0
    X TMP0
    X TMP0
    OP NAND
    SET TMP0
    X target
    X TMP0
    OP ADD
    SET target
ENDMACRO


; set 2 registers to the values of 2 other registers
MACRO COPY16 targetlo targethi sourcelo sourcehi
    OP ADD
    X sourcelo
    X V0
    SET targetlo
    X sourcehi
    SET targethi
ENDMACRO

; bit-invert the value of the operand
MACRO INV8 operand
    OP NAND
    X operand
    X operand
    SET operand
ENDMACRO


; fetch address consisting of two bytes and add the 3rd byte from DBR
MACRO FETCHADDRESS_a rlo rhi rbank        ; = 20
    FETCH rlo                             ; 8
    FETCH rhi                             ; 8
    GET DBR                               ; 3
    SET rbank                             ; 1
ENDMACRO

; fetch two bytes from program and combine with X to get 16-bit address (3rd is DBR)
; Intermediate storage: TMP0
MACRO FETCHADDRESS_a_x rlo rhi rbank
    FETCH rlo
    FETCH rhi
    GET DBR
    SET rbank
    ADD24_16 rlo rhi rbank XLO XHI
ENDMACRO

; fetch two bytes from program and combine with Y to get 16-bit address (3rd is DBR)
; Intermediate storage: TMP0
MACRO FETCHADDRESS_a_y rlo rhi rbank
    FETCH rlo
    FETCH rhi
    GET DBR
    SET rbank
    ADD24_16 rlo rhi rbank YLO YHI
ENDMACRO

; fetch address consisting of three bytes
MACRO FETCHADDRESS_al rlo rhi rbank
    FETCH rlo
    FETCH rhi
    FETCH rbank
ENDMACRO

; fetch three bytes from program and combine with X to get 24-bit address
; Intermediate storage: TMP0
MACRO FETCHADDRESS_al_x rlo rhi rbank
    FETCH rlo
    FETCH rhi
    FETCH rbank
    ADD24_16 rlo rhi rbank XLO XHI
ENDMACRO

; fetch next byte from program and construct the 16-bit address with DHI/DLO (3rd byte is 0)
; Intermediate storage: -
MACRO FETCHADDRESS_d rlo rhi
    FETCH rlo
    X DLO
    X rlo
    OP OVF
    SET rhi
    OP ADD
    SET rlo
    X rhi
    X DHI
    SET rhi
ENDMACRO
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

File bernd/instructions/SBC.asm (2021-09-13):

; subtraction just uses the addition operation by first just 
; inverting the operand. 
; to make this work, the meaning of the C flag needs to be considered
; as inverted by the user program.

; ---- SBC #
    ORG $E900
    FETCH TMP4
    INV8 TMP4
    BRACCU16 SBC_#_16bit
    ADC8V ALO TMP4 CFLAG
    NZ8 ALO
    NEXT
SBC_#_16bit:    
    ADC8 ALO TMP4 CFLAG
    FETCH TMP4
    INV8 TMP4
    ADC8V AHI TMP4 CFLAG
    NZ16 ALO AHI
    NEXT

MACRO SBC_near amode opcode
    ORG opcode >< 00    
    FETCHADDRESS_ >< amode TMP4 TMP5
    LOAD_POSTINC TMP4 TMP5 V0 TMP3
    INV8 TMP3
    BRACCU16 SBC_ >< amode >< _16bit
    ADC8V ALO TMP3 CFLAG
    NZ8 ALO
    NEXT
SBC_ >< amode >< _16bit:    
    ADC8 ALO TMP3 CFLAG
    LOAD TMP4 TMP5 V0 TMP3
    INV8 TMP3
    ADC8V AHI TMP3 CFLAG
    NZ16 ALO AHI
    NEXT
ENDMACRO

MACRO SBC_far amode opcode
    ORG opcode >< 00    
    FETCHADDRESS_ >< amode TMP4 TMP5 TMP6
    LOAD TMP4 TMP5 TMP6 TMP3
    INV8 TMP3
    BRACCU16 SBC_ >< amode >< _y_16bit
    ADC8V ALO TMP3 CFLAG
    NZ8 ALO
    NEXT
SBC_ >< amode >< _y_16bit:    
    ADC8 ALO TMP3 CFLAG
    INC24 TMP4 TMP5 TMP6
    LOAD TMP4 TMP5 TMP6 TMP3
    INV8 TMP3
    ADC8V AHI TMP3 CFLAG
    NZ16 ALO AHI
    NEXT
ENDMACRO
    
    SBC_far  a        $ED
    SBC_far  a_x      $FD
    SBC_far  a_y      $F9
    SBC_far  al       $EF
    SBC_far  al_x     $FF
    SBC_near d        $E5
    SBC_near d_s      $E3
    SBC_near d_x      $F5
    SBC_far  (d)      $F2
    SBC_far  [d]      $E7
    SBC_far  (d_s)_y  $F3
    SBC_far  (d_x)    $E1
    SBC_far  (d)_y    $F1
    SBC_far  [d]_y    $F7

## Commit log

2020-10-26 Migrate from project ByteMachine
    [ALU.sch, Addressing.sch, Control.sch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]
2020-10-29 Working on system board
    [Control.sch, IOSystem.sch, cpuboard.sch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]
2020-10-31 Finished design of system board
    [IOSystem.sch, systemboard.sch]
2020-11-01 Ongoing tweaks
    [IOSystem.sch, systemboard.sch]
2020-11-10 Adjusting hardware to better fit 7400 parts. Small test program.
    [IOSystem.sch, systemboard.sch]
2020-11-11 Extend IO address range to 512 bytes. Allows to map a complete page (256 bytes) of main address range to the extended RAM.
    [IOSystem.sch, systemboard.sch]
2020-11-11 Extend clock for all IO accesses - not only read access.
    [systemboard.sch]
2020-11-12 Introduce a few bit of 74AC logic parts to speed up some critical signals. Use two 74HC gates in tandem to create a more stable clock.
    [Control.sch, cpuboard.sch]
2020-11-14 Export schematics to PDF
2020-11-18 Simple emulator and a few more sample programs
    [Addressing.sch]
2020-11-22 Change CPU control to only use HC parts while not losing speed. It is still possible to run at 11MHz.
    [Control.sch]
2020-11-26 Add immediate addressing mode to DP instruction.
    [Addressing.sch, Control.sch, cpuboard.sch]
2020-11-30 Working serial IO with RTS/CTS on my FT232 USB-to-UART bridge
2020-12-12 Example program to do some serious number crunching. The machine is not running stable yet.
    [systemboard.sch]
2021-04-07 New attempt to create a part-reduced microcontroller architecture
    [controllerboard.sch]
2021-04-10 Modify wiring to for convenient breadboarding
    [controllerboard.sch]
2021-04-12 Complete redesign of basically everything
    [ALU.sch, Addressing.sch, Control.sch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]
2021-04-12 Rework tooling for new architecture
    [controllerboard.sch]
2021-04-13 Get first test program to run
    [controllerboard.sch]
2021-04-15 Design system breadboard Adjust emulator for new architecture
    [controllerboard.sch, mainboard.kicad_pcb, mainboard.sch]
2021-04-15 Prepare sample program to use the full BreadBin computer
2021-04-17 Add macro feature to assembler.
2021-04-19 Redesign memory/io interface for easier wireing on the breadboard. This also uses less ICs.
    [mainboard.sch]
2021-04-19 Fixed address decoding
    [mainboard.sch]
2021-04-24 Restructure memory map for easier compatibility with other designs
    [mainboard.sch]
2021-04-27 Fine-tune resistors of the oscillator
    [controllerboard.sch]
2021-04-30 Change branch instruction to only use the B operator.
    [controllerboard.sch]
2021-04-30 Change address latch interface and software access. Refactor large parts of Bernd to work with new latch interface and make code more compact also.
    [controllerboard.sch, mainboard.sch]
2021-05-13 More instructions. Fix the ASL crash.
    [ADC.asm, CMP.asm, SBC.asm]
2021-05-22 Rework ALU and opoerand stack so it can be easier implemented in 7400 logic
    [ADC.asm]
2021-05-23 Rework schematic for modified architecture
    [CPU.sch, board.sch, controllerboard.sch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]
2021-05-24 Complete ALU design
    [ALU.sch, CPU.sch, board.sch]
2021-05-30 Modify schematic to better match breadboard possibilities.
    [ALU.sch, CPU.sch, board.kicad_pcb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]
2021-05-31 Modify ALU so I can build it with parts that are actually available.
    [ALU.sch, CPU.sch, board.kicad_pcb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]
2021-06-04 Rework ALU to have 4 operand inputs and so it can be built with availbale parts
    [ALU.sch, CPU.sch, board.sch]
2021-06-04 Modify ALU: Remove REV operation and get AVG/HALF/ROR instead.
    [ALU.sch]
2021-06-18 Work on ALU. Implement more 65c816 instructions.
    [CPU.sch]
2021-06-20 Adjust schematics to match actual breadboard
    [ALU.sch, CPU.sch, board.sch]
2021-07-02 Use a 1:2 clock duty cycle (33% low) no wait states are necessary
    [CPU.sch, board.sch]
2021-07-03 Add more instructions (and fix CMP)
    [CMP.asm]
2021-07-09 Emulator mode for board with only bare port IO (no serial communication)
2021-07-24 Fix addressing mode (d),y
    [macros.asm]
2021-08-29 Fix BIT instruction. Read characters without blocking.
    [macros.asm]
2021-11-21 Rework MMU to use a 74HC138 as in the OS816 reference
    [CPU.sch, board.sch]
